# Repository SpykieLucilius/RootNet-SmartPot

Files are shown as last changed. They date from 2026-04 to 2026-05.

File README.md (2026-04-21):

# RootNet-SmartPot

The RootNet-SmartPot is an ESP32-based modular sensing unit designed for intelligent indoor plant monitoring. It serves as the perception layer for the RootNet ecosystem, collecting environmental data and providing immediate local feedback.

## Features
- **Comprehensive Sensing**: Monitors soil moisture, ambient light (Lux/RGB), temperature, and humidity.
- **Local Feedback**: Features an SSD1306 OLED display for real-time status updates (e.g., "Needs Water", "Too Cold", "OK") without network dependency.
- **Power Efficiency**: Optimized for long-term battery operation using ESP32 Deep Sleep cycles.
- **Energy Harvesting**: Supports autonomous operation via a 0.5W solar panel and an integrated LiPo charging circuit.
- **Connectivity**: Transmits telemetry via Wi-Fi to a central RootNet server for data logging and remote monitoring.

## Hardware Components
- **Microcontroller**: Lolin32 V1.0.0 (ESP32)
- **Display**: SSD1306 OLED (0.91", 128x32)
- **Light Sensor**: TCS34725 RGB Color Sensor
- **Moisture Sensor**: Capacitive Soil Moisture Sensor V2.0
- **Climate Sensor**: DHT11 Temperature and Humidity Sensor
- **Energy**: 1000mAh LiPo Battery & 5V / 0.5W Solar Panel
- **Accessories**: 10kΩ Pull-up Resistor, Breadboard, and Jumper Wires

## Repository Structure
```text
RootNet-SmartPot/
├── docs/
│   ├── wiring_diagram.md
│   ├── build_guide.md
│   └── images/
├── firmware/
│   ├── SmartPot_Main/
│   │   └── SmartPot_Main.ino
│   └── tests/
│       ├── oled_test.ino
│       ├── light_test.ino
│       ├── soil_test.ino
│       ├── dht11_test.ino
│       └── all_sensor_test.ino
├── hardware/
│   └── device_list.md
└── README.md

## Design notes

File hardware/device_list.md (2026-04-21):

# List of Devices: RootNet-SmartPot Project

## 1. Lolin32 V1.0.0 (ESP32-based Microcontroller)
* **Role:** Central processing unit for sensor telemetry collection, local display control, and Wi-Fi transmission.
* **Key Features:** Dual-core processor, integrated Wi-Fi/Bluetooth, and a built-in LiPo charging circuit with battery monitoring on GPIO 35.

## 2. SSD1306 OLED Display (0.91")
* **Role:** Local interface for real-time status updates and sensor readings.
* **Key Features:** 128x32 pixel resolution (monochrome), I2C interface, and ultra-low power consumption.

## 3. TCS34725 RGB Color Sensor
* **Role:** Measures ambient light intensity (Lux) and color temperature to assess environmental lighting.
* **Key Features:** High dynamic range, integrated IR-blocking filter, and I2C communication sharing the same bus as the display.

## 4. Capacitive Soil Moisture Sensor V2.0
* **Role:** Measures the dielectric constant of the soil to estimate moisture levels.
* **Key Features:** Capacitive sensing technology (prevents electrode corrosion), 3.3V compatible, and analogue output to GPIO 34.

## 5. DHT11 Temperature and Humidity Sensor
* **Role:** Monitors ambient climate conditions (temperature and humidity) surrounding the plant.
* **Key Features:** Digital sensing via a proprietary single-wire protocol on GPIO 4.

## 6. 10kΩ Resistor
* **Role:** Pull-up resistor for the DHT11 data line.
* **Key Features:** Stabilizes digital communication by preventing the signal line from floating.

## 7. Breadboard and Jumper Wires
* **Role:** Main prototyping platform for circuit assembly and electrical verification.
* **Key Features:** Facilitates solderless component testing and easy hardware iterations.

## 8. Power & Solar Energy System
* **Role:** Provides autonomous power management for long-term remote monitoring.
* **Key Features:** * **Solar Panel:** 5V / 0.5W panel used for energy harvesting.
    * **Battery:** ~1000 mAh LiPo battery for power buffering and overnight operation.
    * **Charging:** The solar panel feeds the Lolin32's onboard TP4054-based charging circuit, which automatically manages the LiPo charging cycle.

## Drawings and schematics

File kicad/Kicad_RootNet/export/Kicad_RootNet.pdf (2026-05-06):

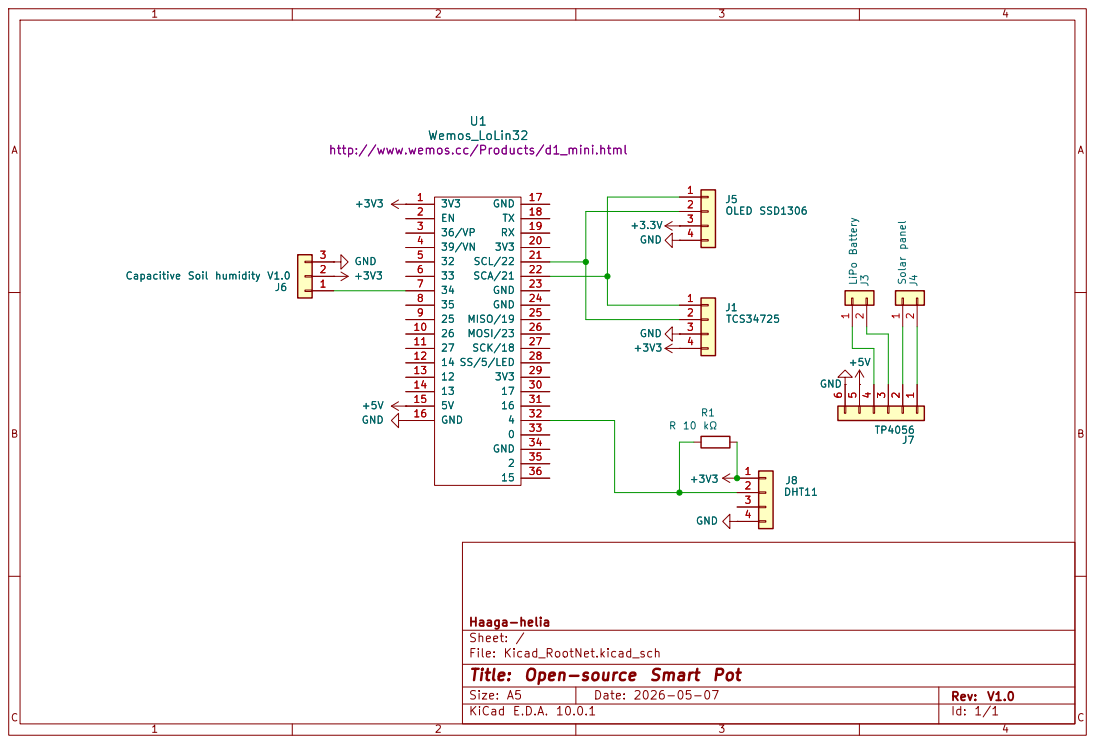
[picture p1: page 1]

http://www.wemos.cc/Products/d1_mini.html 3V3 1

Haaga-helia
Sheet: /
File: Kicad_RootNet.kicad_sch
Title: Open-source Smart Pot

Size: A5 | Rev: V1.0 | C Date: 2026-05-07
KiCad E.D.A. 10.0.1 | Id: 1/1

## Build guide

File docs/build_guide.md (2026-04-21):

# Build Guide: RootNet SmartPot

This guide explains how to assemble the SmartPot sensor module.

## Prerequisites
* Basic soldering skills (for the TCS34725 pins).
* Arduino IDE installed with the following libraries:
  * `Adafruit SSD1306` & `Adafruit GFX`
  * `Adafruit TCS34725`
  * `DHT sensor library` (by Adafruit)

## Step 1: Pin Soldering
If your **TCS34725** (Light Sensor) came without pins:
1. Place the header pins into a breadboard to keep them steady.
2. Place the sensor PCB on top of the pins.
3. Solder each pin carefully at ~350°C.

## Step 2: Breadboard Assembly
1. **Power Rails:** Connect the Lolin32 `3.3V` and `GND` to the breadboard power rails.
2. **I2C Bus:** Connect the **SSD1306 OLED** and the **TCS34725** in parallel to `GPIO 21` (SDA) and `GPIO 22` (SCL).
3. **Soil Sensor:** Connect the **Capacitive Soil Sensor** to `GPIO 34`.
4. **DHT11:** Connect the **DHT11** to `GPIO 4`. 
   * *Critical:* Place a **10kΩ resistor** between the VCC and DATA pins of the DHT11.

## Step 3: Firmware Upload
1. Open `SmartPot_Main.ino` from the `firmware/` folder.
2. Select Lolin32 in the Arduino IDE.
3. Upload the code and check the Serial Monitor (115200 baud).

## Step 4: Verification
* Ensure the OLED displays "Plant OK" or a specific status.
* Check if values update when you cover the light sensor or touch the soil probe.

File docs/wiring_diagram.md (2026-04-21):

# Wiring Diagram: RootNet SmartPot

The RootNet SmartPot uses a combination of I2C, Analogue, and One-Wire protocols. All components are powered by the Lolin32 3.3V output.

## Pin Mapping Table

| Component | Sensor Pin | Lolin32 Pin | Protocol |
| :--- | :--- | :--- | :--- |
| **SSD1306 OLED** | VCC / GND | 3.3V / GND | Power |
| | SDA / SCL | GPIO 21 / 22 | I2C |
| **TCS34725** | VIN / GND | 3.3V / GND | Power |
| | SDA / SCL | GPIO 21 / 22 | I2C (Shared) |
| **Soil Sensor** | VCC / GND | 3.3V / GND | Power |
| | AOUT | GPIO 34 | Analogue |
| **DHT11** | VCC (Pin 1) | 3.3V | Power |
| | DATA (Pin 2)| GPIO 4 | One-Wire |
| | GND (Pin 4) | GND | Power |

## Special Wiring Notes

### I2C Shared Bus
Both the OLED display and the Light Sensor share the same physical wires for SDA and SCL. The ESP32 distinguishes them via their hardware addresses:
* **OLED:** 0x3C
* **TCS34725:** 0x29

### DHT11 Pull-up Resistor
A 10kΩ resistor must be connected between VCC (Pin 1) and DATA (Pin 2) of the DHT11 to ensure stable digital communication.

### Internal Battery Monitoring
The Lolin32 V1.0.0 monitors battery voltage internally via a voltage divider connected to GPIO 35. No external wiring is required for this feature.

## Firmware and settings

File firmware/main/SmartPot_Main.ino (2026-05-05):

/*
 * SmartPot_Main.ino
 *
 * Sensor-module firmware for the smart modular pot project.
 * Targets the Wemos Lolin32 V1.0.0 (ESP32-based).
 *
 * Cycle:
 *   1. Wake from deep sleep (or initial boot)
 *   2. Read sensors: capacitive soil moisture, DHT11 temp/humidity,
 *      TCS34725 light intensity + colour
 *   3. Build a flat JSON payload
 *   4. Connect to Wi-Fi via WiFiMulti (multi-SSID, picks strongest)
 *   5. Resolve the server through mDNS (rootnet.local), fall back to a
 *      per-SSID IP table if mDNS is blocked on the network
 *   6. POST /readings
 *   7. Show readings on the OLED for a short window
 *   8. Power-down sequence (OLED off, Wi-Fi off, Serial.flush())
 *   9. esp_deep_sleep_start() for SLEEP_SECONDS
 *
 */

#include <Wire.h>
#include <WiFi.h>
#include <WiFiMulti.h>
#include <ESPmDNS.h>
#include <HTTPClient.h>
#include <ArduinoJson.h>

#include <Adafruit_GFX.h>
#include <Adafruit_SSD1306.h>
#include <Adafruit_TCS34725.h>
#include <DHT.h>

// ---------- Configuration ---------------------------------------------------

// Sleep duration between cycles (seconds). 600 = 10 minutes.
static const uint64_t SLEEP_SECONDS = 600ULL;

// How long to keep the OLED on after a successful cycle (milliseconds).
static const uint32_t OLED_AWAKE_MS = 15000UL;

// Wi-Fi connection timeout (milliseconds). Falls through to deep sleep on failure.
static const uint32_t WIFI_TIMEOUT_MS = 12000UL;

// HTTP timeout for the POST (milliseconds).
static const uint32_t HTTP_TIMEOUT_MS = 5000UL;

// Server discovery
static const char* SERVER_HOSTNAME = "rootnet";        // resolved as rootnet.local
static const uint16_t SERVER_PORT  = 8080;
static const char* SERVER_PATH     = "/readings";

// Status-line thresholds for the OLED
static const int   SOIL_DRY_THRESHOLD = 2500;
static const float TEMP_COLD          = 18.0f;
static const float TEMP_HOT           = 32.0f;
static const float LUX_LOW            = 200.0f;

// ---------- Pins ------------------------------------------------------------

static const int PIN_SDA      = 21;
static const int PIN_SCL      = 22;
static const int PIN_DHT      = 4;
static const int PIN_SOIL_ADC = 34;

// ---------- Peripherals -----------------------------------------------------

#define OLED_W 128
#define OLED_H 32
Adafruit_SSD1306 display(OLED_W, OLED_H, &Wire, -1);

Adafruit_TCS34725 tcs(TCS34725_INTEGRATIONTIME_50MS, TCS34725_GAIN_4X);

#define DHTTYPE DHT11
DHT dht(PIN_DHT, DHTTYPE);

// ---------- Wi-Fi networks --------------------------------------------------
//
// Each SSID/password pair will be tried by WiFiMulti, which picks whichever
// one is in range with the strongest signal. Add more here as needed.

WiFiMulti wifiMulti;

struct WifiCred {
  const char* ssid;
  const char* pass;
  const char* fallback_ip;   
};

static const WifiCred WIFI_NETWORKS[] = {
  { "home_wifi1",       "REPLACE_WITH_PASSWORD", "192.168.8.100" },
  { "home_wifi2",      "REPLACE_WITH_PASSWORD", "192.168.1.50"  },
  { "phone_hotspot",  "REPLACE_WITH_PASSWORD", "172.20.10.2"   },
};
static const size_t WIFI_NETWORKS_COUNT =
    sizeof(WIFI_NETWORKS) / sizeof(WIFI_NETWORKS[0]);

// ---------- Persistent state ------------------------------------------------

RTC_DATA_ATTR uint32_t bootCount = 0;

// ---------- Utility ---------------------------------------------------------

static void goToDeepSleep() {
  Serial.printf("[step] entering deep sleep for %llu s\n",
                (unsigned long long)SLEEP_SECONDS);

  // Power-down sequence. 
  display.ssd1306_command(SSD1306_DISPLAYOFF);
  WiFi.disconnect(true);
  WiFi.mode(WIFI_OFF);
  Serial.flush();

  esp_sleep_enable_timer_wakeup(SLEEP_SECONDS * 1000000ULL);
  esp_deep_sleep_start();
}

static bool connectWifi() {
  Serial.println("[step] connecting Wi-Fi");

  WiFi.mode(WIFI_STA);
  for (size_t i = 0; i < WIFI_NETWORKS_COUNT; i++) {
    wifiMulti.addAP(WIFI_NETWORKS[i].ssid, WIFI_NETWORKS[i].pass);
  }

  uint32_t start = millis();
  while (wifiMulti.run() != WL_CONNECTED) {
    if (millis() - start > WIFI_TIMEOUT_MS) {
      Serial.println("[warn] Wi-Fi connection timed out");
      return false;
    }
    delay(200);
  }

  Serial.printf("[ok] Wi-Fi connected to %s (%s)\n",
                WiFi.SSID().c_str(), WiFi.localIP().toString().c_str());
  return true;
}

// Resolve the server: try mDNS first, fall back to a per-SSID IP table.
static String resolveServerHost() {
  if (MDNS.begin("smartpot")) {
    IPAddress addr = MDNS.queryHost(SERVER_HOSTNAME);
    if (addr != IPAddress(0, 0, 0, 0)) {
      Serial.printf("[ok] mDNS resolved %s.local -> %s\n",
                    SERVER_HOSTNAME, addr.toString().c_str());
      return addr.toString();
    }
  }

  // Fallback: look up the current SSID in the network table
  String currentSsid = WiFi.SSID();
  for (size_t i = 0; i < WIFI_NETWORKS_COUNT; i++) {
    if (currentSsid == WIFI_NETWORKS[i].ssid) {
      Serial.printf("[warn] mDNS failed; using fallback IP %s\n",
                    WIFI_NETWORKS[i].fallback_ip);
      return String(WIFI_NETWORKS[i].fallback_ip);
    }
  }

  Serial.println("[err] no server address available");
  return String();
}

// ---------- Sensor reads ----------------------------------------------------

struct Reading {
  int   soil_raw;
  float temperature;
  float humidity;
  float lux;
  uint16_t r, g, b, c;
  bool dhtOk;
};

static Reading readAllSensors() {
  Reading rd = {};

  // Soil (analogue)
  rd.soil_raw = analogRead(PIN_SOIL_ADC);

  // Light (TCS34725)
  tcs.getRawData(&rd.r, &rd.g, &rd.b, &rd.c);
  rd.lux = tcs.calculateLux(rd.r, rd.g, rd.b);

  // Temperature / humidity (DHT11)
  rd.temperature = dht.readTemperature();
  rd.humidity    = dht.readHumidity();
  rd.dhtOk = !(isnan(rd.temperature) || isnan(rd.humidity));
  if (!rd.dhtOk) {
    rd.temperature = 0.0f;
    rd.humidity    = 0.0f;
  }

  return rd;
}

// ---------- Payload + POST --------------------------------------------------

static String buildPayload(const Reading& rd) {
  StaticJsonDocument<384> doc;
  doc["mac_address"]   = WiFi.macAddress();
  doc["soil_moisture"] = rd.soil_raw;
  doc["temperature"]   = rd.temperature;
  doc["humidity"]      = rd.humidity;
  doc["light_lux"]     = rd.lux;
  doc["light_red"]     = rd.r;
  doc["light_green"]   = rd.g;
  doc["light_blue"]    = rd.b;

  String out;
  serializeJson(doc, out);
  return out;
}

static bool postReading(const String& host, const String& payload) {
  WiFiClient client;
  HTTPClient http;

  String url = "http://" + host + ":" + String(SERVER_PORT) + SERVER_PATH;
  Serial.printf("[step] POST %s\n", url.c_str());

  http.setTimeout(HTTP_TIMEOUT_MS);
  if (!http.begin(client, url)) {
    Serial.println("[err] http.begin failed");
    return false;
  }
  http.addHeader("Content-Type", "application/json");

  int status = http.POST(payload);
  http.end();

  Serial.printf("[%s] POST %d\n", (status >= 200 && status < 300) ? "ok" : "err",
                status);
  return (status >= 200 && status < 300);
}

// ---------- OLED ------------------------------------------------------------

static const char* statusLabel(const Reading& rd) {
  if (!rd.dhtOk) return "DHT err";
  if (rd.soil_raw > SOIL_DRY_THRESHOLD) return "Water needed";
  if (rd.temperature < TEMP_COLD) return "Too cold!";
  if (rd.temperature > TEMP_HOT)  return "Too hot!";
  if (rd.lux < LUX_LOW)           return "Needs light";
  return "Plant OK";
}

static void drawReadings(const Reading& rd) {
  display.clearDisplay();
  display.setTextSize(1);
  display.setTextColor(SSD1306_WHITE);

  display.setCursor(0, 0);
  display.printf("T=%.1fC H=%.0f%%\n", rd.temperature, rd.humidity);
  display.printf("Soil=%d Lux=%.0f\n", rd.soil_raw, rd.lux);
  display.printf("#%lu %s\n", (unsigned long)bootCount, statusLabel(rd));

  display.display();
}

// ---------- Setup / Loop ----------------------------------------------------

void setup() {
  Serial.begin(115200);
  delay(50);

  bootCount++;
  Serial.printf("\n=== Wake cycle #%lu ===\n", (unsigned long)bootCount);

  // 12-bit ADC for the soil sensor
  analogReadResolution(12);

  // I2C for OLED + TCS34725
  Wire.begin(PIN_SDA, PIN_SCL);

  // OLED
  if (!display.begin(SSD1306_SWITCHCAPVCC, 0x3C)) {
    Serial.println("[err] OLED init failed");
    // continue anyway - the cycle should still report data
  } else {
    display.clearDisplay();
    display.setTextSize(1);
    display.setTextColor(SSD1306_WHITE);
    display.setCursor(0, 0);
    display.printf("Boot #%lu\nWaking...\n", (unsigned long)bootCount);
    display.display();
  }

  // Light sensor
  if (!tcs.begin()) {
    Serial.println("[warn] TCS34725 not found");
  }

  // DHT11
  dht.begin();

  // Read sensors
  Serial.println("[step] reading sensors");
  Reading rd = readAllSensors();
  Serial.printf("T=%.1fC H=%.0f%% Soil=%d Lux=%.0f -> %s\n",
                rd.temperature, rd.humidity, rd.soil_raw, rd.lux,
                statusLabel(rd));

  // Show readings on OLED while we deal with the network
  drawReadings(rd);

  // Wi-Fi
  if (!connectWifi()) {
    Serial.println("[warn] no Wi-Fi this cycle, sleeping");
    delay(OLED_AWAKE_MS); 
    goToDeepSleep();
  }

  // Resolve server and POST
  String host = resolveServerHost();
  if (host.length() > 0) {
    String payload = buildPayload(rd);
    Serial.printf("[step] payload (%u bytes)\n", payload.length());
    postReading(host, payload);
  }

  // Hold the OLED on for a moment so a passer-by can read the values
  Serial.printf("[step] holding OLED for %lu ms\n", (unsigned long)OLED_AWAKE_MS);
  delay(OLED_AWAKE_MS);

  // Sleep
  goToDeepSleep();
}

void loop() {
  // Never reached: setup() always ends in deep sleep.
}

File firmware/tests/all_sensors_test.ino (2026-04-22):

#include <Wire.h>
#include <Adafruit_GFX.h>
#include <Adafruit_SSD1306.h>
#include <Adafruit_TCS34725.h>
#include <DHT.h>

// --- Configuration & Pin Definitions ---
#define SCREEN_WIDTH 128
#define SCREEN_HEIGHT 32
#define OLED_ADDR    0x3C

#define SOIL_PIN     34
#define DHTPIN       4
#define DHTTYPE      DHT11

#define I2C_SDA      21
#define I2C_SCL      22

// --- Thresholds for Plant Status ---
const int SOIL_DRY_THRESHOLD = 2500;
const float TEMP_COLD_THRESHOLD = 15.0;

// --- Object Initialization ---
Adafruit_SSD1306 display(SCREEN_WIDTH, SCREEN_HEIGHT, &Wire, -1);
Adafruit_TCS34725 tcs = Adafruit_TCS34725(TCS34725_INTEGRATIONTIME_50MS, TCS34725_GAIN_4X);
DHT dht(DHTPIN, DHTTYPE);

void setup() {
  // Initialize Serial for debugging at 115200 baud
  Serial.begin(115200);
  
  // Initialize I2C bus for the Lolin32
  Wire.begin(I2C_SDA, I2C_SCL);
  
  // Initialize OLED Display
  if(!display.begin(SSD1306_SWITCHCAPVCC, OLED_ADDR)) {
    Serial.println(F("OLED initialization failed"));
    for(;;);
  }

  // Initialize Sensors
  tcs.begin();
  dht.begin();
  
  // Configure ESP32 ADC resolution to 12-bit (0-4095 range)
  analogReadResolution(12);

  // Initial Screen Setup
  display.clearDisplay();
  display.setTextSize(1);
  display.setTextColor(SSD1306_WHITE);
  display.setCursor(0,0);
  display.println(F("RootNet Initialized"));
  display.display();
  delay(1000);
}

void loop() {
  // 1. Read Light Intensity (I2C)
  uint16_t r, g, b, c;
  tcs.getRawData(&r, &g, &b, &c);
  uint16_t lux = tcs.calculateLux(r, g, b);

  // 2. Read Soil Moisture (Analog)
  int soil_value = analogRead(SOIL_PIN);

  // 3. Read Climate Data (Digital 1-wire)
  float temp = dht.readTemperature();
  float hum = dht.readHumidity();

  // Handle DHT reading errors
  if (isnan(temp) || isnan(hum)) {
    temp = 0.0;
    hum = 0.0;
  }

  // 4. Print Data to Serial Monitor
  Serial.print(F("Temp: ")); Serial.print(temp);
  Serial.print(F("C | Hum: ")); Serial.print(hum);
  Serial.print(F("% | Soil: ")); Serial.print(soil_value);
  Serial.print(F(" | Lux: ")); Serial.println(lux);

  // 5. Update OLED Display
  display.clearDisplay();
  display.setCursor(0, 0);
  
  // Line 1: Climate data
  display.printf("T:%.1fC  H:%.0f%%\n", temp, hum);
  
  // Line 2: Soil and Light values
  display.printf("Soil:%d  Lux:%d\n", soil_value, lux);
  
  // Line 3: Decision Logic based on thresholds
  display.println(F("---------------------"));
  if (soil_value > SOIL_DRY_THRESHOLD) {
    display.print(F("STATUS: Water Needed"));
  } else if (temp < TEMP_COLD_THRESHOLD) {
    display.print(F("STATUS: Too Cold!"));
  } else {
    display.print(F("STATUS: Plant OK"));
  }

  // Push buffer to the physical screen
  display.display();

  // Wait 2 seconds before the next update
  delay(2000);
}

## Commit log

2026-04-21 Adding code to test if the screen is wired correctly
2026-04-21 Adding wiring schema
2026-04-21 fixing type of device
2026-04-21 Adding code to test if the light sensor is wired correctly
2026-04-21 Adding code to test if the soil sensor is wired correctly
2026-04-21 Adding code to test if the temp sensor is wired correctly
2026-04-21 Adding code to test if all the sensors works together correctly
2026-04-21 Adding wiring_diagram.md
2026-04-21 Adding list of devices used
2026-04-22 adding all sensor test
2026-05-05 removing battery voltage measure for now
2026-05-06 feat: adding KiCad schematics
    [Kicad_RootNet.kicad_pcb, Kicad_RootNet.kicad_sch]
